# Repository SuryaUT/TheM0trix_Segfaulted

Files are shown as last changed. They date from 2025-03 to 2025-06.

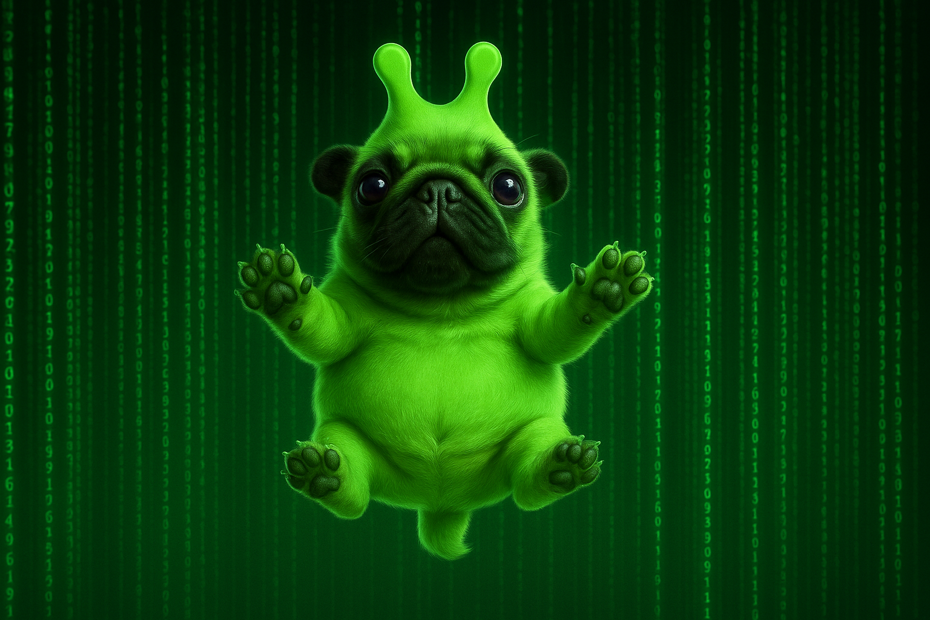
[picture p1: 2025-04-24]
Images/Binary Images/GEEB.png

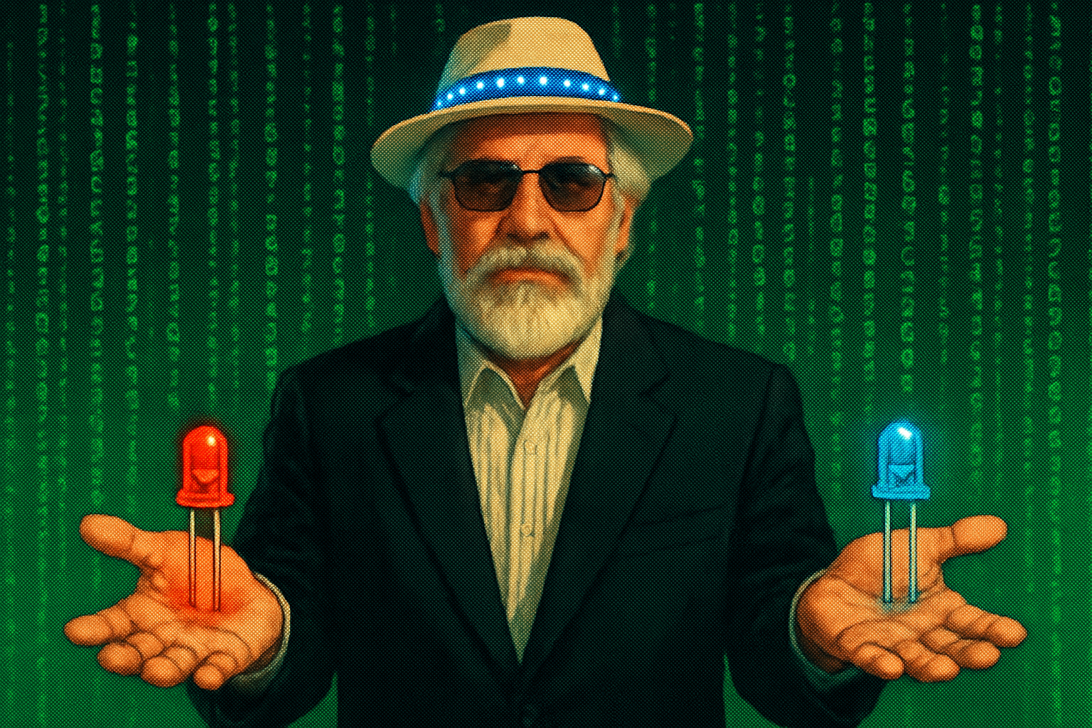
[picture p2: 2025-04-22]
Images/Binary Images/VANO.png

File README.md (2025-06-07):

# 🕶️ The M0+rix: Segfaulted

A Matrix-themed multiplayer FPS built entirely on the MSPM0G3507 microcontroller. Featuring low-level graphics rendering via raycasting, joystick control, UART-based multiplayer, and a fully custom 3D-printed enclosure.

---

## Table of Contents

* [🎮 Game Description](#-game-description)
* [🔥 Features](#-features)
* [🚀 Getting Started](#-getting-started)
* [🔩 Parts List](#-parts-list)
* [🎮 Controls](#-controls)
* [🖼️ Screenshots / Demo](#️-screenshots--demo)
* [🛠️ Enclosure](#-enclosure)
* [👥 Authors](#-authors)

---

## 🎮 Game Description

Reality is a pointer… and you just dereferenced NULL.

Welcome to **The M0+rix: Segfaulted**, a handheld first-person shooter where the only way out is through the system’s deepest vulnerabilities. Running on the MSPM0 microcontroller, this game turns embedded systems into battlegrounds, with PVP combat over UART and a retro-style 3D world.

Dodge enemy fire, navigate the simulation, and exploit every loophole in the code—because in this world, even one bad instruction could bring everything crashing down. Are you the debugger or just another broken process?

---

## 🔥 Features:

* ✅ First-person shooter with a Matrix-inspired digital battlefield
* ✅ Real-time PVP over UART – battle your opponent in low-level style
* ✅ Optimized for MSPM0 – embedded gaming meets high-speed action
* ✅ Handheld experience – take the simulation anywhere
* ✅ Segfault or escape? – The system is unstable, and only one player will survive

💾 Flash in. Boot up. Overwrite reality.

---

## 🚀 Getting Started

1.  **Clone this repo**

    ```bash
    git clone [https://github.com/SuryaUT/TheM0trix_Segfaulted.git](https://github.com/SuryaUT/TheM0trix_Segfaulted.git)
    ```

2.  **Import into Code Composer Studio** <br>
    Open CCS. Go to **File > Import > Code Composer Studio Projects**. Select the cloned folder. Make sure the target is set to **MSPM0G3507**. Click **Finish**.

3.  **Build and Flash** <br>
    Plug in the LaunchPad. Press the build button. Flash to the board.

---

## 🔩 Parts List

| Ref. | Value | Datasheet | Footprint | Qty |
| :--- | :--- | :--- | :--- | :--- |
| C1 | 1uF | ~ | ECE319K:CP\_Radial\_Tantal200mil | 1 |
| C2 | 4.7uF | ~ | ECE319K:CP\_Radial\_Tantal200mil | 1 |
| C3, C4 | 0.1uF | ~ | ECE319K:C\_Axial\_200mil | 2 |
| D1, D4 | LED | Link 1, Link 2 | ECE319K:LED\_D5.0mm | 2 |
| H1, H2, H3, H4 | – | ~ | ECE319K:MountingHole\_4\_40 | 4 |
| J1 | AudioJack | ~ | ECE319K:Jack\_3.5mm\_CUI\_SJ1-3523N\_Horizontal | 1 |
| J2 | Speaker | ~ | ECE319K:PinHeader\_1x02\_P2.54mm\_Vertical | 1 |
| J3 | UART1 | ~ | ECE319K:PinHeader\_1x03\_P2.54mm\_Vertical | 1 |
| J6 | GND | ~ | ECE319K:Testpoint\_1x02\_P2.54mm | 1 |
| J7 | DACOUT | ~ | ECE319K:Testpoint\_1x02\_P2.54mm | 1 |
| J8 | Joystick | SparkFun | ECE319K:SparkfunJoystick | 1 |
| JP1 | TExaS | ~ | ECE319K:PinHeader\_1x03\_P2.54mm\_Vertical | 1 |
| JP2, JP3, JP4 | Jumper\_3\_Open | ~ | ECE319K:PinHeader\_1x03\_P2.54mm\_Vertical | 3 |
| R1 | 470Ω | Resistors | ECE319K:R\_Axial\_DIN0204\_L3.6mm\_D1.6mm\_P7.62mm\_Horizontal | 1 |
| R4–R8 | 1.5kΩ | Resistors | ECE319K:R\_Axial\_DIN0204\_L3.6mm\_D1.6mm\_P7.62mm\_Horizontal | 5 |
| R9–R11 | 12kΩ | Resistors | ECE319K:R\_Axial\_DIN0204\_L3.6mm\_D1.6mm\_P7.62mm\_Horizontal | 3 |
| R12–R15, R17, R19 | 10kΩ | Resistors | ECE319K:R\_Axial\_DIN0204\_L3.6mm\_D1.6mm\_P7.62mm\_Horizontal | 6 |
| R16 | 20kΩ | Resistors | ECE319K:R\_Axial\_DIN0204\_L3.6mm\_D1.6mm\_P7.62mm\_Horizontal | 1 |
| R18 | 220Ω | Resistors | ECE319K:R\_Axial\_DIN0204\_L3.6mm\_D1.6mm\_P7.62mm\_Horizontal | 1 |
| SW1 | RELOAD | ~ | ECE319K:SW\_PUSH\_6mm | 1 |
| SW2 | LEFT | ~ | ECE319K:SW\_PUSH\_6mm | 1 |
| SW3 | SWAP | ~ | ECE319K:SW\_PUSH\_6mm | 1 |
| SW4 | RIGHT | ~ | ECE319K:SW\_PUSH\_6mm | 1 |
| SW5 | SHOOT | ~ | ECE319K:Side\_Switch | 1 |
| TP1 | 3.3V | ~ | ECE319K:Testpoint\_1x02\_P2.54mm | 1 |
| U2 | LP-MSPM0G3507 | TI Dev Board | ECE319K:ti\_LP\_MSPM0G3507 | 1 |
| U3 | MCP34119P | Datasheet | ECE319K:DIP-8\_W7.62mm\_LongPads | 1 |
| U4 | HiLetGo\_ST7735R | Display | ECE319K:hiletgo\_st7735r | 1 |
| U5 | ULN2003B | ULN2003B | ECE319K:DIP-16\_W7.62mm | 1 |
| U6 | TSOP31438 | TSOP31438 | ECE319K:TSOP31438 | 1 |
| ~ | SD Card | ~ | ~ | 1 |
| ~ | Wire Pack | ~ | ~ | 1 |

*Note: Side\_Switch was a custom footprint made by placing surface mount plates the width of switch legs on the front and back of the PCB, such that a switch could be soldered to face away from the side of the PCB, acting like a trigger.*

📦 Full schematic & PCB design files available in “M0+rixPCBFiles” folder

---

## 🎮 Controls

| Control | Action |
| :--- | :--- |
| Joystick | Move Forward, Backward, Strafe Left and Right |
| Trigger Button | Fire weapon |
| Left Button | Rotate Left |
| Right Button | Rotate Right |
| Top Button | Reload/Respawn |
| Bottom Button | Switch Item |

---

## 🖼️ Screenshots / Demo

Gameplay demo available on YouTube [here](https://www.youtube.com/watch?v=fk33UKtkELA).
gameplay

---

## 🛠️ Enclosure

* Designed in Fusion 360
* Snap-fit top cover
* Gamepad-style ergonomic shell
  
enclosure_1
enclosure_2

---

## 👥 Authors

* Elijah Silguero
* Surya Balaji

Special thanks to Dr. Yerrabali, Dr. Valvano, and Dr. Tiwari at The University of Texas at Austin for their instruction and help with this project!

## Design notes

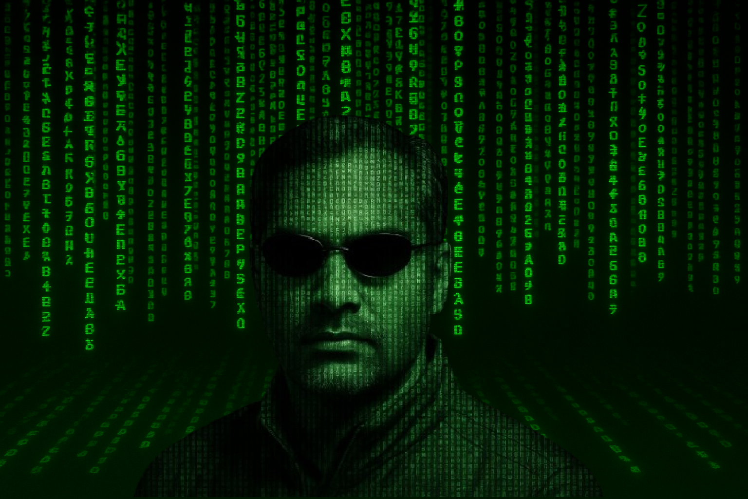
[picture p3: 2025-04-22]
Images/Binary Images/LDSC.png

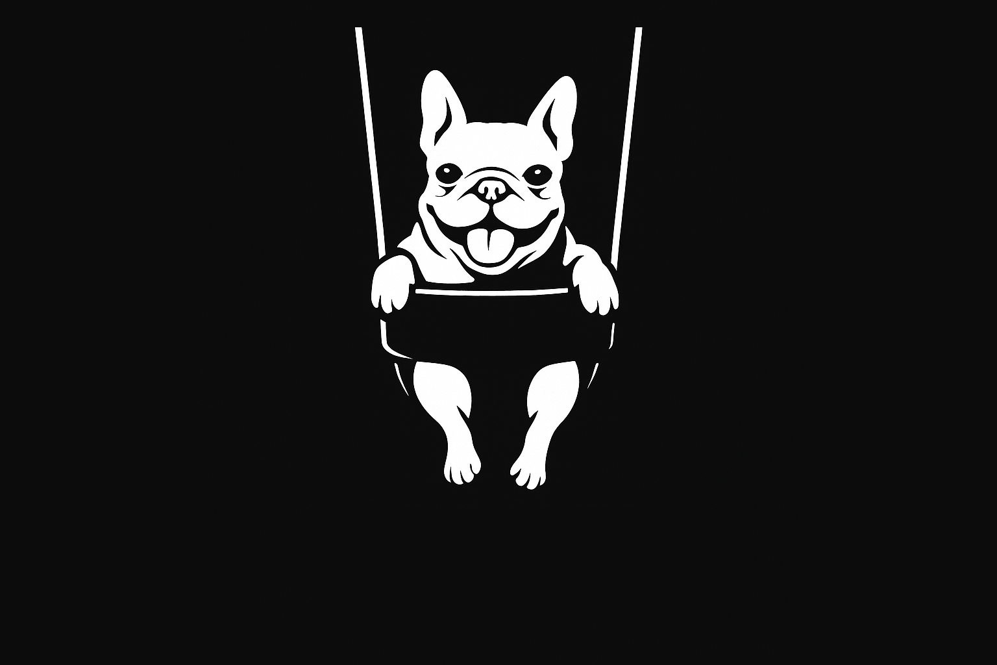
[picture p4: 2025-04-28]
Images/Binary Images/SCBMENU.png

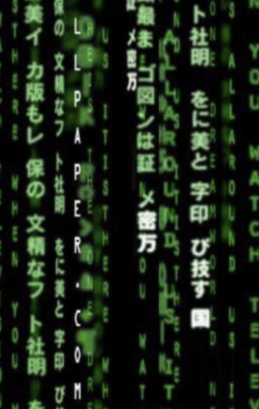
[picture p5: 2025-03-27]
Textures/matrix.bmp

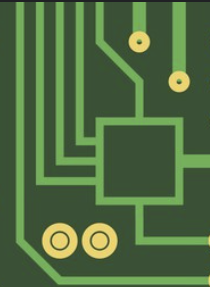
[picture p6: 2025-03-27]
Textures/circuitBoardTex2.bmp

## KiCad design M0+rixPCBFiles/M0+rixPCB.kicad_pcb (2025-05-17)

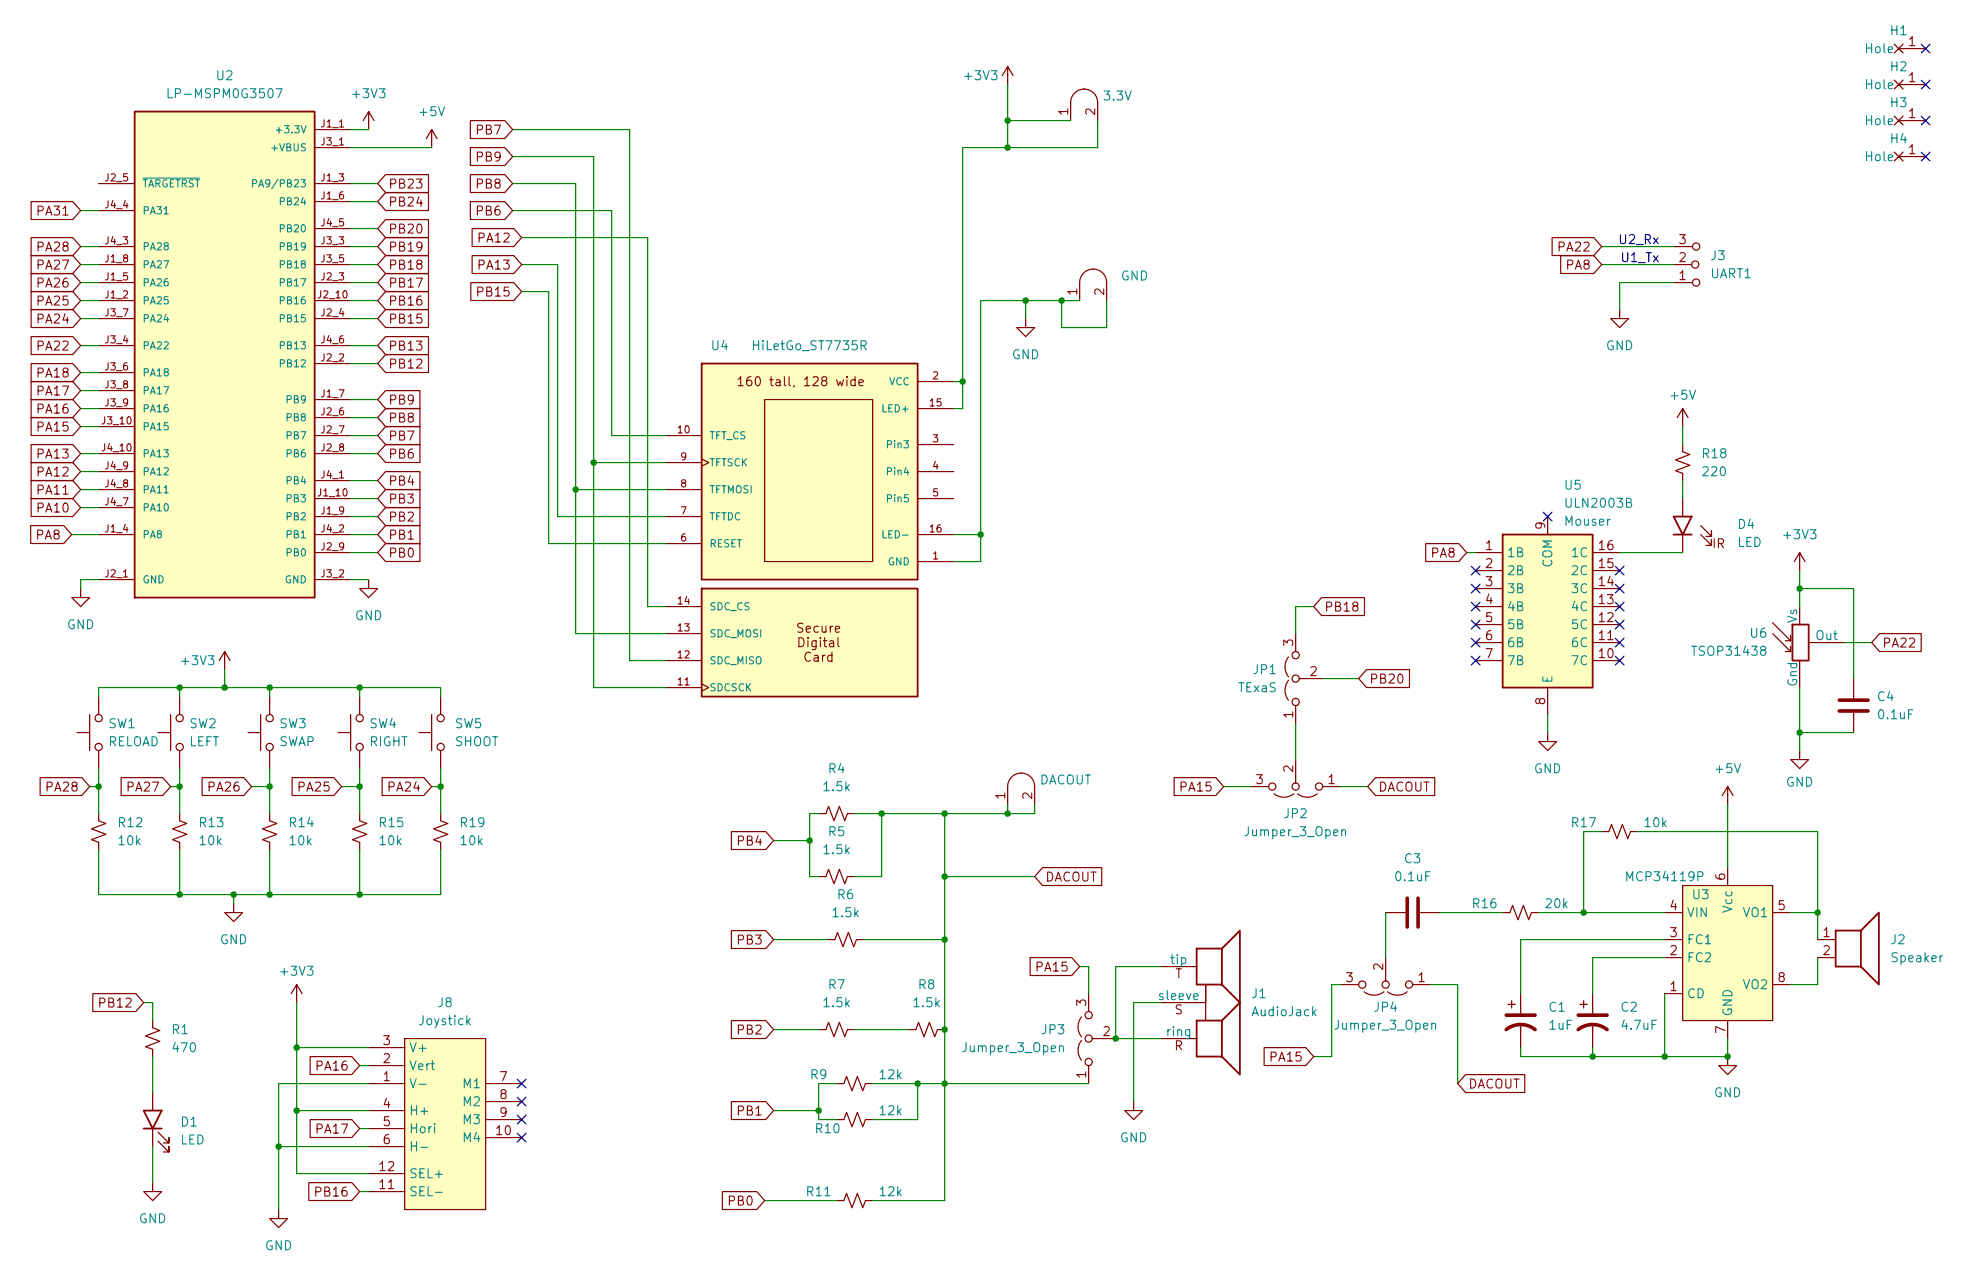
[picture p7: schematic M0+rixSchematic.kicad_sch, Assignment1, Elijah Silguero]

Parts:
C1: 1uF; CP_Radial_Tantal200mil
C2: 4.7uF; CP_Radial_Tantal200mil
C3, C4: 0.1uF; C_Axial_200mil
D1, D4: LED; LED_D5.0mm
H1, H2, H3, H4: MountingHole_4_40
J1: AudioJack; Jack_3.5mm_CUI_SJ1-3523N_Horizontal
J2: Speaker; PinHeader_1x02_P2.54mm_Vertical
J3: UART1; PinHeader_1x03_P2.54mm_Vertical
J6: GND; Testpoint_1x02_P2.54mm
J7: DACOUT; Testpoint_1x02_P2.54mm
J8: Joystick; SparkfunJoystick
JP1: TExaS; PinHeader_1x03_P2.54mm_Vertical
JP2, JP3, JP4: Jumper_3_Open; PinHeader_1x03_P2.54mm_Vertical
R1: 470; R_Axial_DIN0204_L3.6mm_D1.6mm_P7.62mm_Horizontal
R4, R5, R6, R7, R8: 1.5k; R_Axial_DIN0204_L3.6mm_D1.6mm_P7.62mm_Horizontal
R9, R10, R11: 12k; R_Axial_DIN0204_L3.6mm_D1.6mm_P7.62mm_Horizontal
R12, R13, R14, R15, R17, R19: 10k; R_Axial_DIN0204_L3.6mm_D1.6mm_P7.62mm_Horizontal
R16: 20k; R_Axial_DIN0204_L3.6mm_D1.6mm_P7.62mm_Horizontal
R18: 220; R_Axial_DIN0204_L3.6mm_D1.6mm_P7.62mm_Horizontal
SW1: RELOAD; SW_PUSH_6mm
SW2: LEFT; SW_PUSH_6mm
SW3: SWAP; SW_PUSH_6mm
SW4: RIGHT; SW_PUSH_6mm
SW5: SHOOT; Side_Switch
TP1: 3.3V; Testpoint_1x02_P2.54mm
U2: LP-MSPM0G3507; ti_LP_MSPM0G3507
U3: MCP34119P; DIP-8_W7.62mm_LongPads
U4: HiLetGo_ST7735R; hiletgo_st7735r
U5: ULN2003B; DIP-16_W7.62mm
U6: TSOP31438

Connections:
+3V3: C4.1, J8.3 (V+), J8.4 (H+), J8.12 (SEL+), SW1.2, SW2.2, SW3.2, SW4.2, SW5.2, TP1.1 (A), TP1.2 (B), U2.J1_1 (+3.3V), U4.2 (VCC), U4.15 (LED+), U6.2 (Vs)
+5V: R18.1, U2.J3_1 (+VBUS), U3.6 (Vcc)
DACOUT: J7.1 (A), J7.2 (B), JP2.1 (A), JP3.1 (A), JP4.1 (A), R4.1, R5.1, R6.1, R8.1, R9.1, R10.1, R11.1
GND: C1.2, C2.2, C4.2, D1.1 (K), J1.S (sleeve), J3.1 (A), J6.1 (A), J6.2 (B), J8.1 (V-), J8.6 (H-), R12.2, R13.2, R14.2, R15.2, R19.2, U2.J2_1 (GND), U2.J3_2 (GND), U3.1 (CD), U3.7 (GND), U4.1 (GND), U4.16 (LED-), U5.8 (E), U6.1 (Gnd)
unnamed: C3.2, R16.2
unnamed: D1.2 (A), R1.2
unnamed: D4.2 (A), R18.2
unnamed: D4.1 (K), U5.16 (1C)
unnamed: J1.R (ring), J1.T (tip), JP3.2 (C)
unnamed: JP1.1 (A), JP2.2 (C)
unnamed: C3.1, JP4.2 (C)
unnamed: R7.1, R8.2
unnamed: C1.1, U3.3 (FC1)
unnamed: C2.1, U3.2 (FC2)
unnamed: R16.1, R17.2, U3.4 (VIN)
unnamed: J2.1, R17.1, U3.5 (VO1)
unnamed: J2.2, U3.8 (VO2)
PA8: J3.2 (B), U2.J1_4 (PA8), U5.1 (1B)
PA10: U2.J4_7 (PA10)
PA11: U2.J4_8 (PA11)
PA12: U2.J4_9 (PA12), U4.14 (SDC_CS)
PA13: U2.J4_10 (PA13), U4.7 (TFTDC)
PA15: JP2.3 (B), JP3.3 (B), JP4.3 (B), U2.J3_10 (PA15)
PA16: J8.2 (Vert), U2.J3_9 (PA16)
PA17: J8.5 (Hori), U2.J3_8 (PA17)
PA18: U2.J3_6 (PA18)
PA22: J3.3 (C), U2.J3_4 (PA22), U6.3 (Out)
PA24: R19.1, SW5.1, U2.J3_7 (PA24)
PA25: R15.1, SW4.1, U2.J1_2 (PA25)
PA26: R14.1, SW3.1, U2.J1_5 (PA26)
PA27: R13.1, SW2.1, U2.J1_8 (PA27)
PA28: R12.1, SW1.1, U2.J4_3 (PA28)
PA31: U2.J4_4 (PA31)
PB0: R11.2, U2.J2_9 (PB0)
PB1: R9.2, R10.2, U2.J4_2 (PB1)
PB2: R7.2, U2.J1_9 (PB2)
PB3: R6.2, U2.J1_10 (PB3)
PB4: R4.2, R5.2, U2.J4_1 (PB4)
PB6: U2.J2_8 (PB6), U4.10 (TFT_CS)
PB7: U2.J2_7 (PB7), U4.12 (SDC_MISO)
PB8: U2.J2_6 (PB8), U4.8 (TFTMOSI), U4.13 (SDC_MOSI)
PB9: U2.J1_7 (PB9), U4.9 (TFTSCK), U4.11 (SDCSCK)
PB12: R1.1, U2.J2_2 (PB12)
PB13: U2.J4_6 (PB13)
PB15: U2.J2_4 (PB15), U4.6 (RESET)
PB16: J8.11 (SEL-), U2.J2_10 (PB16)
PB17: U2.J2_3 (PB17)
PB18: JP1.3 (B), U2.J3_5 (PB18)
PB19: U2.J3_3 (PB19)
PB20: JP1.2 (C), U2.J4_5 (PB20)
PB23: U2.J1_3 (PA9/PB23)
PB24: U2.J1_6 (PB24)

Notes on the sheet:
U2_Rx
U1_Tx

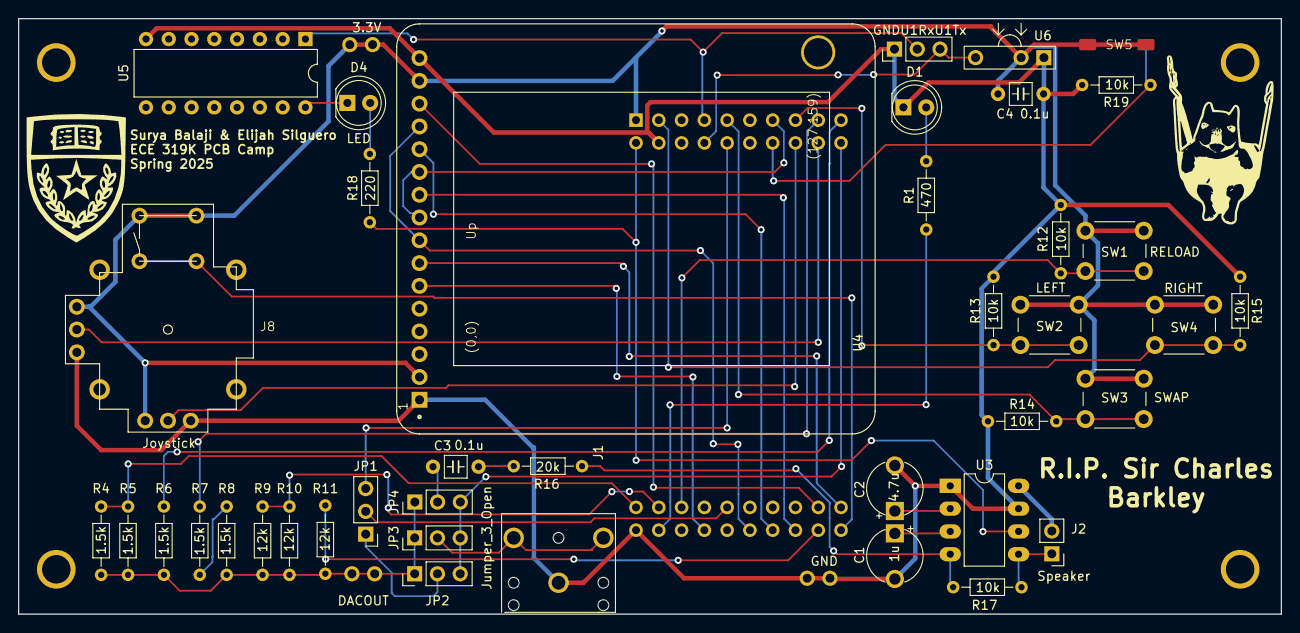
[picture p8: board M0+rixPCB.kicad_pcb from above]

Board: 2 copper layers, 140.8 x 66.4 mm, 48 parts (1 on the bottom side), 43 nets.

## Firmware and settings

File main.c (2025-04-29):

#include <stdio.h>
 #include <stdint.h>
 #include <stdlib.h>
 #include <math.h>
 #include "Async_Delay.h"
 #include "Sync.h"
#include "UART1.h"
#include "UART2.h"
 #include "ti/devices/msp/msp.h"
 #include "ST7735_SDC.h"
 #include "../inc/SPI.h"
 #include "../inc/Clock.h"
 #include "../inc/LaunchPad.h"
 #include "../inc/ADC.h"
 #include "Graphics.h"
 #include "Sounds.h"
 #include "sprites.h"
 #include "Buffer.h"
 #include "Input.h"
 #include "Inventory.h"
 #include "Items.h"
 #include "SoundSD.h"


// Player state
Player self = {
  22, // X position
  12, // Y position
  -1, // X direction
  0, // Y direction
  0, // Plane direction
  .66,
  50, // Health
  1, // is vulnerable
  0, // is shooting
  0, // number of kills
  0 // is on target
};

Player other = {
  22,
  12,
  -1,
  0,
  0,
  .66,
  50,
  1,
  0,
  0,
  0
};

uint8_t healthCode = 1;

extern uint8_t language;
extern const char* const* deathScreenTexts[];


Inventory inventory = {0, 3, {}, 0};

void initRandom(){
  uint32_t randomSeed;
  ADC0_Init(5, ADCVREF_VDDA);
  randomSeed = ADC0_In() * ADC0_In();
  srand(randomSeed);
}

void SystemInit() {
  __disable_irq();
  initRandom();
  Clock_Init80MHz(0);
  LaunchPad_Init();
  Sound_Init(80000000/11000, 0);
  Input_Init();
  __enable_irq();
  Graphics_Init();
  Sync_Init();
}

void respawnPlayer(){
  // Reset inventory
  inventory.index = inventory.size - 1;
  while (inventory.index > 0){
    Inventory_removeCurrent(&inventory);
  }
  Item* current = Inventory_currentItem(&inventory);
  current->ammo = current->mag_ammo;
  current->tot_ammo = current->start_ammo;
  current->enabled = 1;
  
  // Random location
  uint8_t respawnX;
  uint8_t respawnY;
  // Temporary invulnerability
  start_delay(1000, &self.isVulnerable);

  getRandomMapPos(&respawnX, &respawnY);

  self.posX = respawnX + .5;
  self.posY = respawnY + .5;

  // Reset some graphics
  self.isShooting = 0;
  hitTimer = 0;
}

void DeathScreen(){
    Inventory_currentItem(&inventory)->enabled = 0;
    ST7735_DrawBitmapFromSDC(0, 127, (!IS_DOMINANT_CONTROLLER) ? "GEEB.bin" : "TWEO.bin", 160, 128);
    
    uint8_t i = 0;
    const char * const *texts = deathScreenTexts[language];

    while (texts[i]) {
        if (i == 0) {
            ST7735_DrawTextBoxS(0, 0, 160, texts[i], ST7735_WHITE, ST7735_WHITE, 2, 1, 0);
        } 
        else if (texts[i+1] == 0) {
            ST7735_DrawTextBoxS(0, 112, 160, texts[i], ST7735_WHITE, ST7735_WHITE, 1, 1, 0);
        } 
        else {
            ST7735_FillRect(0, 74, 160, 8, ST7735_BLACK);
            ST7735_DrawTextBoxS(0, 74, 160, texts[i], ST7735_WHITE, ST7735_BLACK, 1, 1, 0);
            if (texts[i+1] != 0 && texts[i+2] != 0) Clock_Delay1ms(1000);
        }
        i++;
    }

    if (other.playerHealth <= 0) other.playerHealth = 50; // If they died at the same time, we know they'll respawn

    while (!(GPIOA->DIN31_0 & ((1<<28) | (1<<27)))) {}
}


uint8_t isPlaying;
void GameLoop(){
  self.playerHealth = other.playerHealth = 50;
  self.kills = other.kills = 0;
  SoundEffects_enable();
  Inventory_add(&inventory, &pistol);
  RandomizeSprites();
  // Starting weapon
  respawnPlayer();
  isPlaying = 1;
  while(isPlaying) {
   if (other.playerHealth == 0){
    Sprites[0].scale = 0; 
    healthCode = DEADCODE;
   }else {
    Sprites[0].scale = 5;
   }
   RenderScene();
  
   // In case of death
   if (self.playerHealth <= 0){
    DeathScreen();
    if (GPIOA->DIN31_0 & (1<<27)) {
      isPlaying = 0;
      healthCode = RESTARTCODE;
    }
    else{
      self.playerHealth = 50;
      healthCode = RESPAWNCODE;
      other.kills++;
      respawnPlayer();
    }
   }
  }
}

void Menus_Run(void);

int main() {
  SystemInit();

  while (1){
    Menus_Run();
    GameLoop();
  }
}

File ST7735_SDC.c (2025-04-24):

/***************************************************
  This is a library for the Adafruit 1.8" SPI display.
  This library works with the Adafruit 1.8" TFT Breakout w/SD card
  ----> http://www.adafruit.com/products/358
  as well as Adafruit raw 1.8" TFT display
  ----> http://www.adafruit.com/products/618

  Check out the links above for our tutorials and wiring diagrams
  These displays use SPI to communicate, 4 or 5 pins are required to
  interface (RST is optional)
  Adafruit invests time and resources providing this open source code,
  please support Adafruit and open-source hardware by purchasing
  products from Adafruit!

  Written by Limor Fried/Ladyada for Adafruit Industries.
  MIT license, all text above must be included in any redistribution
 ****************************************************/

// ST7735_SDC.c
// Runs on MSPM0G3507
// Low level drivers for the ST7735 160x128 LCD based off of
// the file described above.
//    16-bit color, 128 wide by 160 high LCD
// Daniel Valvano
// April 11, 2024
// Augmented 7/17/2014 to have a simple graphics facility
// Augmented for SDC 4/11/2024
// Modified for use of CS (simultaneous with other SPI slaves) 3/28/2016

/*

 Copyright 2024 by Jonathan W. Valvano, valvano@mail.utexas.edu
    You may use, edit, run or distribute this file
    as long as the above copyright notice remains
 THIS SOFTWARE IS PROVIDED "AS IS".  NO WARRANTIES, WHETHER EXPRESS, IMPLIED
 OR STATUTORY, INCLUDING, BUT NOT LIMITED TO, IMPLIED WARRANTIES OF
 MERCHANTABILITY AND FITNESS FOR A PARTICULAR PURPOSE APPLY TO THIS SOFTWARE.
 VALVANO SHALL NOT, IN ANY CIRCUMSTANCES, BE LIABLE FOR SPECIAL, INCIDENTAL,
 OR CONSEQUENTIAL DAMAGES, FOR ANY REASON WHATSOEVER.
 For more information about my classes, my research, and my books, see
 http://users.ece.utexas.edu/~valvano/
 */

// hardware connections
// **********ST7735 TFT and SDC*******************
// ST7735
// Backlight (pin 10)     to +3.3 V
// MISO (pin 9)           to SPI1 POCI: PB7
// SCK (pin 8)            to SPI1 SCLK: PB9
// MOSI (pin 7)           to SPI1 PICO: PB8
// TFT_CS (pin 6)         to GPIO:  PB6
// CARD_CS (pin 5)        to PA12 (GPIO)
// Data/Command (pin 4)   to PA13 (GPIO), high for data, low for command
// RESET (pin 3)          to PB15 (GPIO)
// VCC (pin 2)            to +3.3 V
// Gnd (pin 1)            to ground





// **********HiLetgo ST7735 TFT and SDC (SDC not tested)*******************
// ST7735
// LED-   (pin 16) TFT, to ground
// LED+   (pin 15) TFT, to +3.3 V
// SD_CS  (pin 14) SDC, to PA12 chip select
// MOSI   (pin 13) SDC, to PB8 MOSI
// MISO   (pin 12) SDC, to PB7 MISO
// SCK    (pin 11) SDC, to serial clock
// CS     (pin 10) TFT, to PB6  GPIO
// SCL    (pin 9)  TFT, to PB9  SPI1 SCLK
// SDA    (pin 8)  TFT, to PB8  MOSI SPI1 PICO
// A0     (pin 7)  TFT, to PA13 Data/Command, high for data, low for command
// RESET  (pin 6)  TFT, to PB15 reset (GPIO), low to reset
// NC     (pins 3,4,5)
// VCC    (pin 2)       to +3.3 V
// GND    (pin 1)       to ground



#include <ti/devices/msp/msp.h>
#include "ST7735_SDC.h"
#include "../inc/SPI.h"
#include "../inc/Clock.h"
#include "file.h"
#include <stdio.h>
#include <stdlib.h>
#define SDC_CS_PA12 1
#define TFT_CS_LOW()     (GPIOB->DOUTCLR31_0 = (1<<6))   // PB6 low
#define TFT_CS_HIGH()    (GPIOB->DOUTSET31_0 = (1<<6))   // PB6 high

// PA12 output used for SDC CS
#if SDC_CS_PA12
#define SDC_CS           GPIOA
#define SDC_CS_PIN       (1<<12)         // CS controlled by software
#define SDC_CS_LOW()     (SDC_CS->DOUTCLR31_0 = SDC_CS_PIN)   // PA12 low
#define SDC_CS_HIGH()    (SDC_CS->DOUTSET31_0 = SDC_CS_PIN)   // PA12 high
#endif
// disk_initialize will initialize SPI1 for both TFT and SDC
// 16 rows (0 to 15) and 21 characters (0 to 20)
// Requires (11 + size*size*6*8) bytes of transmission for each character
uint32_t StX=0; // position along the horizontal axis 0 to 20
uint32_t StY=0; // position along the vertical axis 0 to 15
uint16_t StTextColor = ST7735_YELLOW;

#define ST7735_NOP     0x00
#define ST7735_SWRESET 0x01
#define ST7735_RDDID   0x04
#define ST7735_RDDST   0x09

#define ST7735_SLPIN   0x10
#define ST7735_SLPOUT  0x11
#define ST7735_PTLON   0x12
#define ST7735_NORON   0x13

#define ST7735_INVOFF  0x20
#define ST7735_INVON   0x21
#define ST7735_DISPOFF 0x28
#define ST7735_DISPON  0x29
#define ST7735_CASET   0x2A
#define ST7735_RASET   0x2B
#define ST7735_RAMWR   0x2C
#define ST7735_RAMRD   0x2E

#define ST7735_PTLAR   0x30
#define ST7735_COLMOD  0x3A
#define ST7735_MADCTL  0x36

#define ST7735_FRMCTR1 0xB1
#define ST7735_FRMCTR2 0xB2
#define ST7735_FRMCTR3 0xB3
#define ST7735_INVCTR  0xB4
#define ST7735_DISSET5 0xB6

#define ST7735_PWCTR1  0xC0
#define ST7735_PWCTR2  0xC1
#define ST7735_PWCTR3  0xC2
#define ST7735_PWCTR4  0xC3
#define ST7735_PWCTR5  0xC4
#define ST7735_VMCTR1  0xC5

#define ST7735_RDID1   0xDA
#define ST7735_RDID2   0xDB
#define ST7735_RDID3   0xDC
#define ST7735_RDID4   0xDD

#define ST7735_PWCTR6  0xFC

#define ST7735_GMCTRP1 0xE0
#define ST7735_GMCTRN1 0xE1
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

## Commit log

2025-03-27 Added another .bmp texture and updated converter
    made texture 7 a different circuit board texture and updated converter to create const instead of static const arrays
2025-03-27 Adjusted printed c array format
2025-04-02 Added sprint ability from joystick button
2025-04-04 Fixed inventory game logic bugs
    [main.c]
2025-04-04 Fixed ammo game logic bugs
    [Input.c]
2025-04-05 Begin UART
2025-04-06 UART char transmission
2025-04-06 Implimented cross controller UART position updates
2025-04-07 added interrupt for uart transmission
2025-04-07 more uart debugging
2025-04-07 more uart
2025-04-07 fix uart bugs
2025-04-08 Updated agent sprite and reset UART functionality
2025-04-08 Refactored UART Reception, fixed other player flicker
    [Input.c, UART1.c, UART2.c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]
2025-04-09 UART fixed with position and health sync
    [Input.c, main.c]
2025-04-09 Reorganized synchronization functions, fixed medkit glitch
    [Input.c, Sync.c, main.c]
2025-04-11 Added rifle w/rapidfire (needs ground sprite and UART testing) and slowed rotate speed
2025-04-18 A bunch of changes, bug fixes, added profs, etc.
    [Sync.c, main.c]
2025-04-24 Added Railgun & Fixed Sprite Spawn Bug
    [Input.c, Sync.c]
2025-04-24 interrupt based menu sync
2025-04-24 fix restart menu bug
    [main.c]
2025-04-25 fix shotgun damage discrepancy
    [Input.c, main.c, menus.c]
2025-04-28 Fix menu return bug
    [menus.c]
2025-04-28 fix sound bug at end of dialogue
    [Sync.c]
2025-05-30 Added PCB Files
    [M0+rixPCB.kicad_pcb, M0+rixSchematic.kicad_sch]
